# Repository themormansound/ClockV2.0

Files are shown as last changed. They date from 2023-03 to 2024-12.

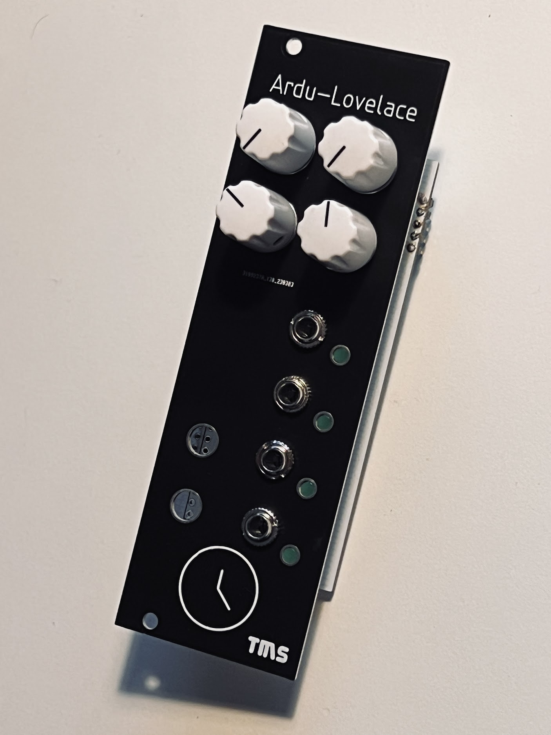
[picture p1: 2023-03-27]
Image.JPG

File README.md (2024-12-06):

# ClockV2.0
An arduino nano based Euro module for making clock code come to life

10ish Volt outputs on digital pins 8,9,10 and 11

4 pots connected to A1, A2, A3 and A4

2 led tactile switches on D2 and D3 (interrupt pins on nano) leds hang off pins D4 and D5

Included is some sample code



If you go ahead and build this, ping me and let me know. 

Build notes, Make sure you solder in the arduino LAST, otherwise you wont be able to do the switches or the pair of components underneath.

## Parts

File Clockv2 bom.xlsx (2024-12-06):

Comment | Designator | Footprint | Descripton
1K | R1 R2 R3 R4 R5 R6 R7 R8 R9 R10 R11 R12 | R0805 | 1K Ohm, 1% 0805 resistors
10K | R14 R15 R16 | R0805 | 10K Ohm, 1% 0805 resistors
100K | R13 | R0805 | 100K Ohm, 1% 0805 resistors
120R | R17 R18 | R0805 | 120 Ohm, 1% 0805 resistors
100n | C1 C2 C3 C4 | C0805K | 100nF, 50v 0805 capacitors
100uF | C5 | PANASONIC_B | 100uF, 50v 5mmx5mm electrolytic capacitors
LM321MF | IC1 IC2 IC3 IC4 | SOT23-5 | LM321MF General Purpose Amplifier 1 Circuit SOT-23-5
1N4007 | D5 | SOD-123 | any generic power diode will work, I use 1N4148W-7F
B100K | VR1 VR2 VR3 VR4 | RK09 | 9mm snap in style, alps RK09 or similar
SW1 SW2 | PB6149L | PB6149L | https://www.tme.eu/en/details/pb6149l-1/keypad-switches/highly-electric/
POWER | SV1 | 10 PIN HEADER
LED | D1 D2 D3 D4 | 3mm LED | any 3mm led will work here. (you could use 5mm ones too, but you'll have to drill the panel out)
JACK | U1 U2 U3 U4 | Thonkicon Jack | Standard thonkicon style jacks (WQP518MA) get em from Aliexpress
AN | ARDUINO_NANO | Arduino Nano | Arduino nano board

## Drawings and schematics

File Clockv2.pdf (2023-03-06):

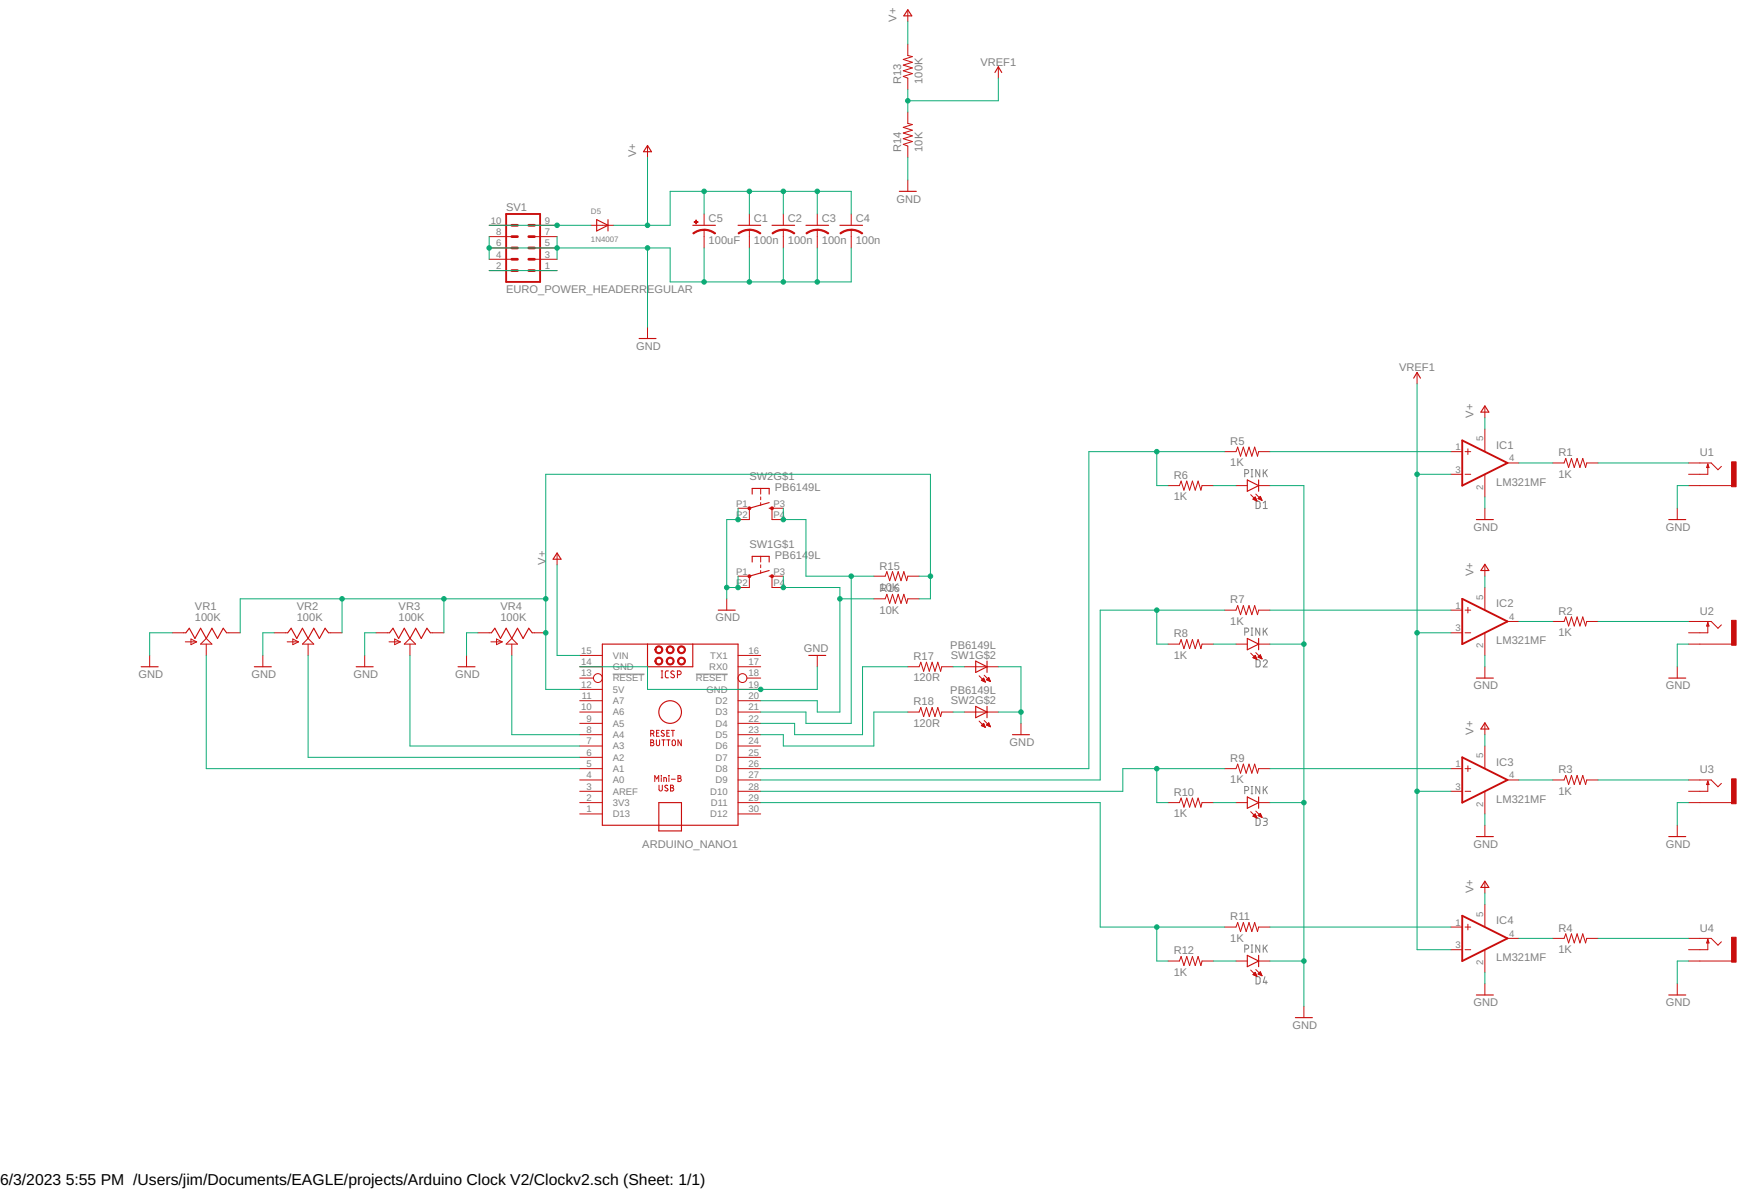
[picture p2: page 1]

6/3/2023 5:55 PM /Users/jim/Documents/EAGLE/projects/Arduino Clock V2/Clockv2.sch (Sheet: 1/1)

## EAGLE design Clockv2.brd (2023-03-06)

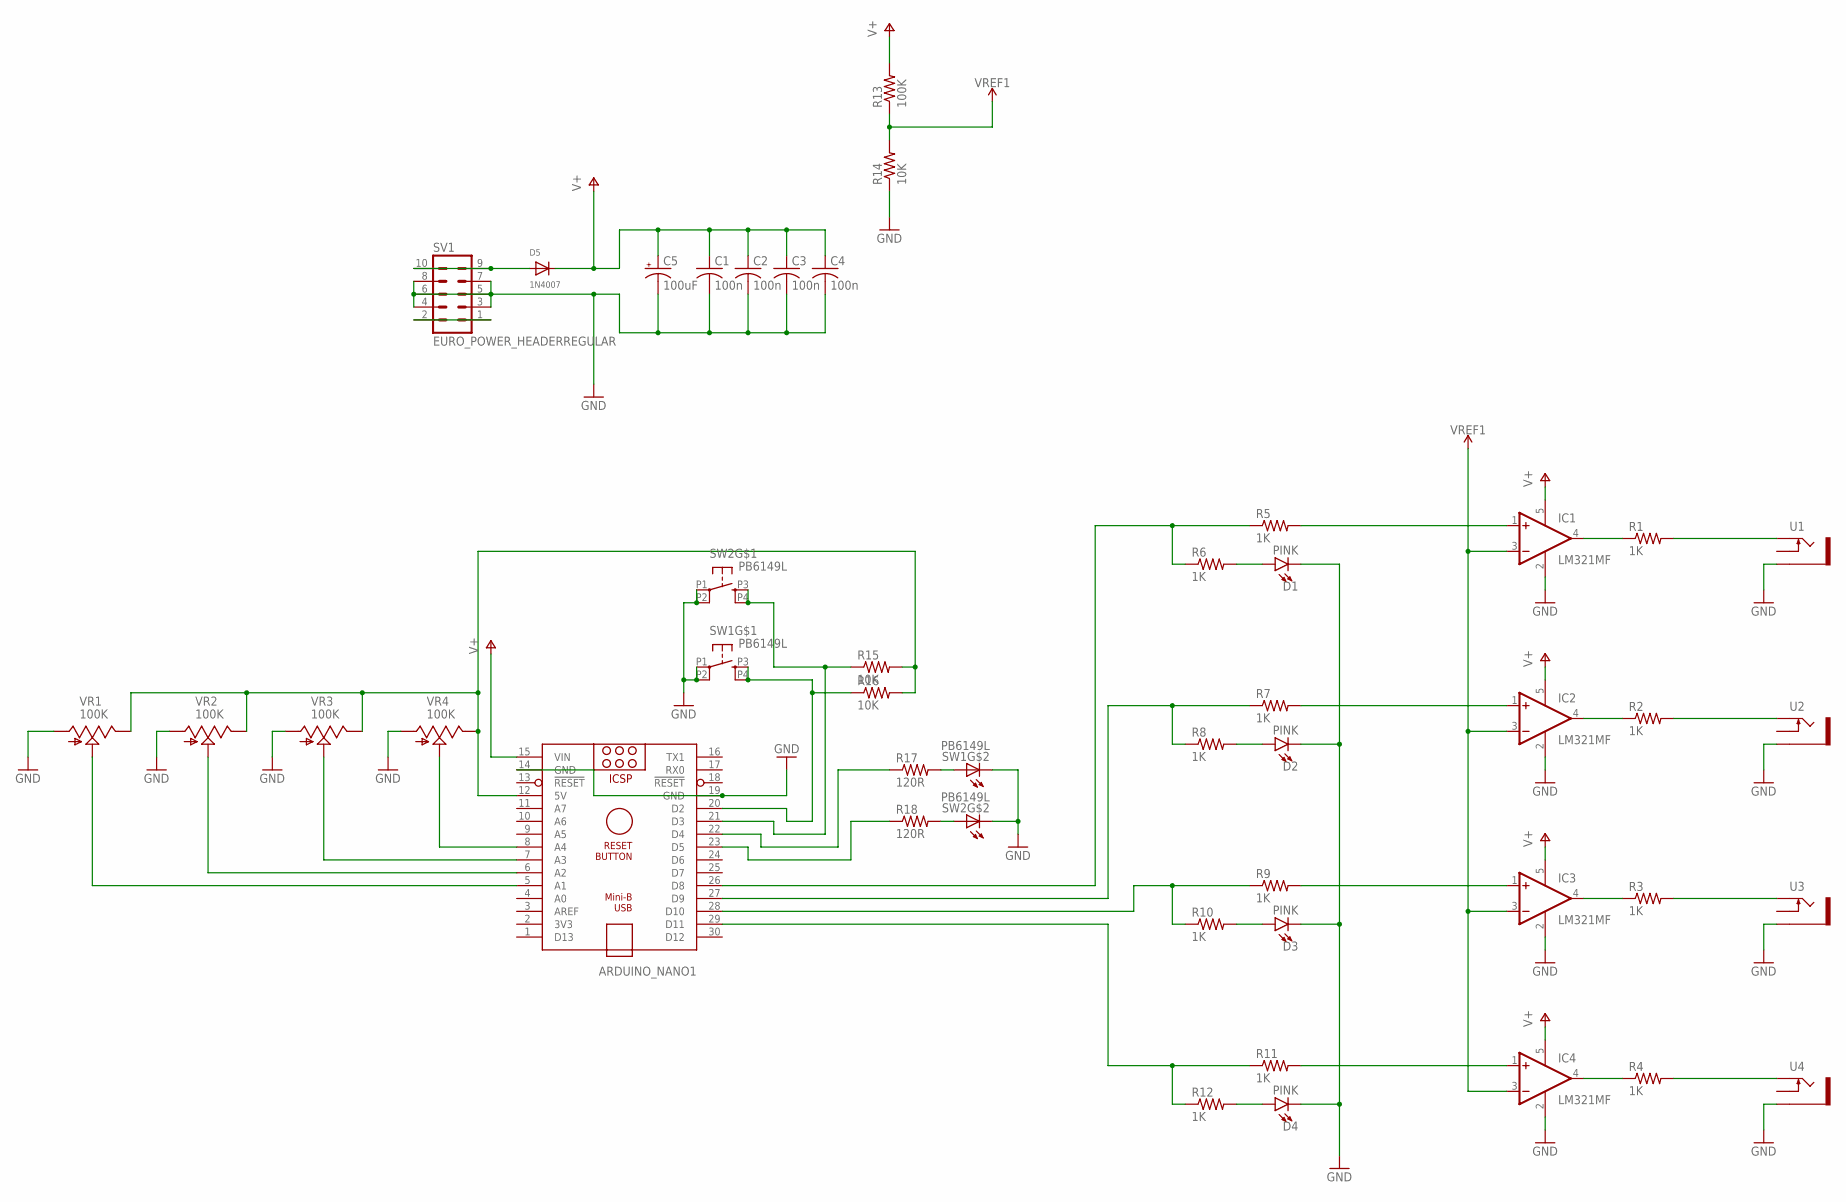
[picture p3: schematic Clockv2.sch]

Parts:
ARDUINO_NANO1: ARDUINO_NANO
C1, C2, C3, C4: 100n; C0805K
C5: 100uF; PANASONIC_B
D1, D2, D3, D4: PINK; LED_3MM
D5: 1N4007; SOD-123
IC1, IC2, IC3, IC4: LM321MF; SOT23-5
R1, R2, R3, R4, R5, R6, R7, R8, R9, R10, R11, R12: 1K; R0805
R13: 100K; R0805
R14, R15, R16: 10K; R0805
R17, R18: 120R; R0805
SV1: EURO_POWER_HEADERREGULAR; EURO_POWER_HEADER
SW1, SW2: PB6149L
U1, U2, U3, U4: THONKICONNNEW; WQP-PJ301M-12_JACK
VR1, VR2, VR3, VR4: 100K; 9MM_SNAP-IN_POT

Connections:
GND: ARDUINO_NANO1.14 (GND), ARDUINO_NANO1.19 (GND), C1.2, C2.2, C3.2, C4.2, C5.-, D1.K (C), D2.K (C), D3.K (C), D4.K (C), IC1.2 (V-), IC2.2 (V-), IC3.2 (V-), IC4.2 (V-), R14.1, SV1.3, SV1.4, SV1.5, SV1.6, SV1.7, SV1.8, SW1.L2 (C), SW1.P1, SW1.P2 (P1), SW2.L2 (C), SW2.P1, SW2.P2 (P1), U1.P$3_SLEEVE (SLEEVE), U2.P$3_SLEEVE (SLEEVE), U3.P$3_SLEEVE (SLEEVE), U4.P$3_SLEEVE (SLEEVE), VR1.1 (A), VR2.1 (A), VR3.1 (A), VR4.1 (A)
unnamed: IC1.4 (OUT), R1.1
unnamed: IC2.4 (OUT), R2.1
unnamed: IC3.4 (OUT), R3.1
unnamed: IC4.4 (OUT), R4.1
unnamed: R1.2, U1.P$1_TIP (TIP)
unnamed: R2.2, U2.P$1_TIP (TIP)
unnamed: R3.2, U3.P$1_TIP (TIP)
unnamed: R4.2, U4.P$1_TIP (TIP)
unnamed: ARDUINO_NANO1.28 (D10), R9.1, R10.1
unnamed: ARDUINO_NANO1.26 (D8), R5.1, R6.1
unnamed: ARDUINO_NANO1.27 (D9), R7.1, R8.1
unnamed: ARDUINO_NANO1.29 (D11), R11.1, R12.1
unnamed: D1.A, R6.2
unnamed: ARDUINO_NANO1.12 (5V), R15.2, R16.2, VR1.3 (E), VR2.3 (E), VR3.3 (E), VR4.3 (E)
unnamed: ARDUINO_NANO1.20 (D2), R16.1, SW1.P3 (S), SW1.P4 (S1)
unnamed: D2.A, R8.2
unnamed: ARDUINO_NANO1.21 (D3), R15.1, SW2.P3 (S), SW2.P4 (S1)
unnamed: IC2.1 (+IN), R7.2
unnamed: IC1.1 (+IN), R5.2
unnamed: IC3.1 (+IN), R9.2
unnamed: D5.A, SV1.9, SV1.10
unnamed: D3.A, R10.2
unnamed: ARDUINO_NANO1.8 (A4), VR4.2 (S)
unnamed: IC4.1 (+IN), R11.2
unnamed: D4.A, R12.2
unnamed: ARDUINO_NANO1.7 (A3), VR3.2 (S)
unnamed: ARDUINO_NANO1.6 (A2), VR2.2 (S)
unnamed: ARDUINO_NANO1.5 (A1), VR1.2 (S)
unnamed: R17.2, SW1.L1 (A)
unnamed: R18.2, SW2.L1 (A)
unnamed: ARDUINO_NANO1.22 (D4), R17.1
unnamed: ARDUINO_NANO1.23 (D5), R18.1
unnamed: SV1.1, SV1.2
V+: ARDUINO_NANO1.15 (VIN), C1.1, C2.1, C3.1, C4.1, C5.+, D5.C, IC1.5 (V+), IC2.5 (V+), IC3.5 (V+), IC4.5 (V+), R13.2
VREF1: IC1.3 (-IN), IC2.3 (-IN), IC3.3 (-IN), IC4.3 (-IN), R13.1, R14.2

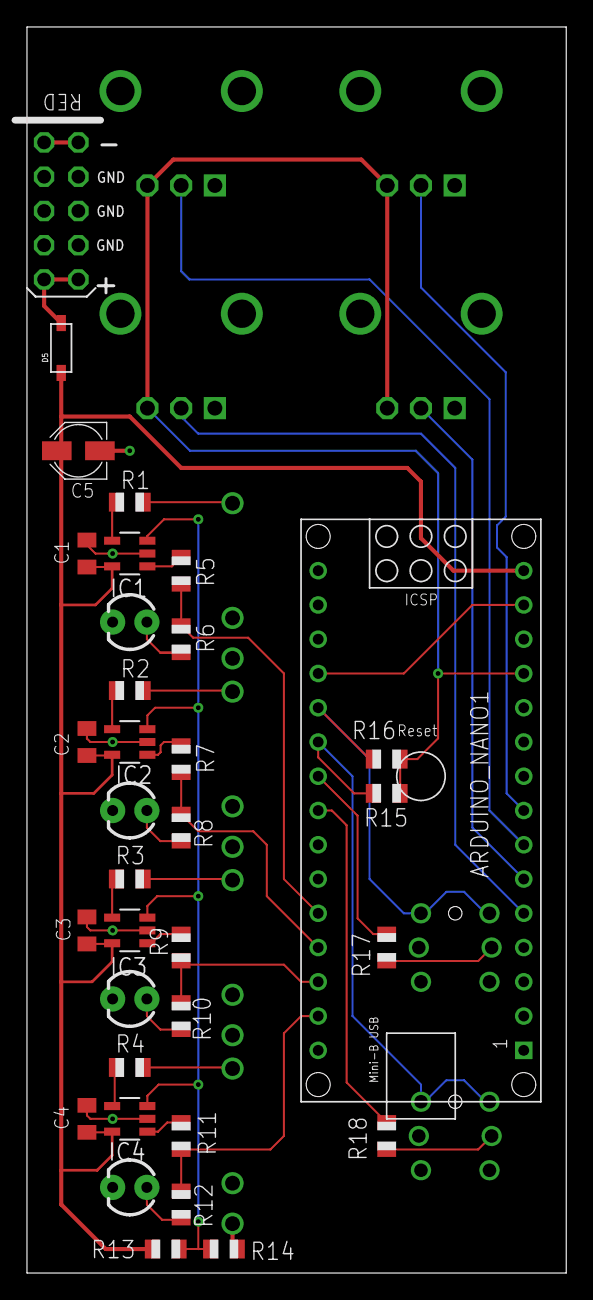
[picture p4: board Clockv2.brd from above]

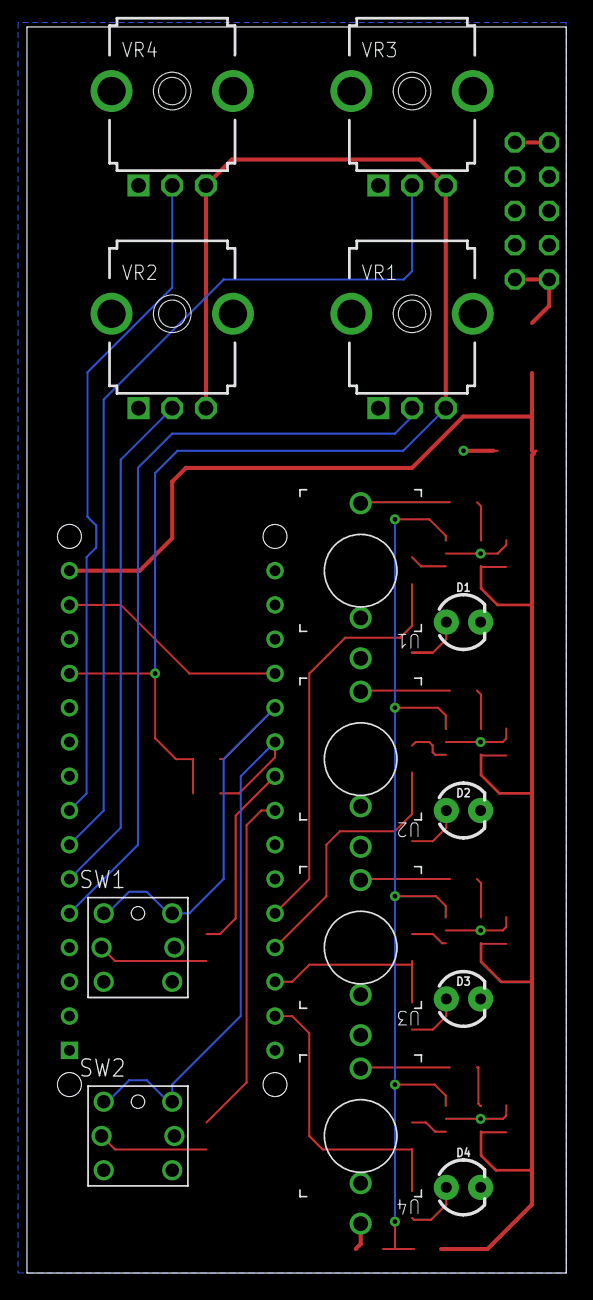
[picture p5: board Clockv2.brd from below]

Board: 2 copper layers, 40.0 x 92.4 mm, 44 parts (14 on the bottom side), 36 nets.

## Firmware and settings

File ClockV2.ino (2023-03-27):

#include <SimpleTimer.h>


SimpleTimer timer;
int count = 0;


void setup() {
  Serial.begin(9600);
  pinMode(8, OUTPUT);
  pinMode(9, OUTPUT);
  pinMode(10, OUTPUT);
  pinMode(11, OUTPUT); 
}

bool started = false;
int priority = 0;
int tapX = 0;
int tapactual;
int tap_time;
int time_actual;
int input1X = 0;
float BPM; 
int max_BPM = 500; /* Max BPM*/
int min_BPM = 60;  /*Min BPM */
int max_time = ((1/(min_BPM/60)) * 1000);
int min_time = ((1/(max_BPM/60)) * 1000);


void loop() {
  
  if (!started) {
    cycle_on();
    started = true;
  }
  
  timer.run();

  

}


/*********************************************************************/



void cycle_off() {
  digitalWrite(8, LOW);
  digitalWrite(9, LOW);
  digitalWrite(10, LOW);
  digitalWrite(11, LOW);

  count++;

  if (count == 8) {
    count = 0;
  }
}



/*********************************************************************/


void cycle_on() {

  switch (count) {
    case 0:
      digitalWrite(8, HIGH);
      digitalWrite(9, HIGH);
      digitalWrite(10, HIGH);
      digitalWrite(11, HIGH);
      break;

    case 1:
      digitalWrite(8, HIGH);
      break;

    case 2:
      digitalWrite(8, HIGH);
      digitalWrite(9, HIGH);
      break;

    case 3:
      digitalWrite(8, HIGH);
      break;
  
    case 4:
      digitalWrite(8, HIGH);
      digitalWrite(9, HIGH);
      digitalWrite(10, HIGH);
      break;

    case 5:
      digitalWrite(8, HIGH);
      break;

    case 6:
      digitalWrite(8, HIGH);
      digitalWrite(9, HIGH);
      break;

    case 7:
      digitalWrite(8, HIGH);
      break;
  }

  int input1 = analogRead(A1);
  int input2 = analogRead(A2);

  if (priority == 0){
     BPM = map(input1, 0, 1023, min_BPM, max_BPM);
     
  }
  
  if (priority == 1){
     BPM = (60000 / tap_time);
    
     
  }


  if (input1X - input1 > 5){
    priority = 0;
  }
  if (input1X - input1 < -5){
    priority = 0;
  }

  input1X = input1;
  
  
  


  
  float duration_percentage =  map(input2, 0, 1023, 1, 90);
 
  int cycletime = (60000/BPM);

  float cycle_start = cycletime;
  float cycle_stop = (cycletime * (duration_percentage/100));


  timer.setTimeout(cycle_start, cycle_on);
  timer.setTimeout(cycle_stop, cycle_off);

}

/*********************************************************************/

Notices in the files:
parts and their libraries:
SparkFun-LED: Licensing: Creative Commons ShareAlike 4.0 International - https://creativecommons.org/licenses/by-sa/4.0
